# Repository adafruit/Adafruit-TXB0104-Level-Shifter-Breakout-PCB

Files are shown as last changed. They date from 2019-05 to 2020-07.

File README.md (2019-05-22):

## Adafruit TXB0104 Level Shifter Breakout PCB
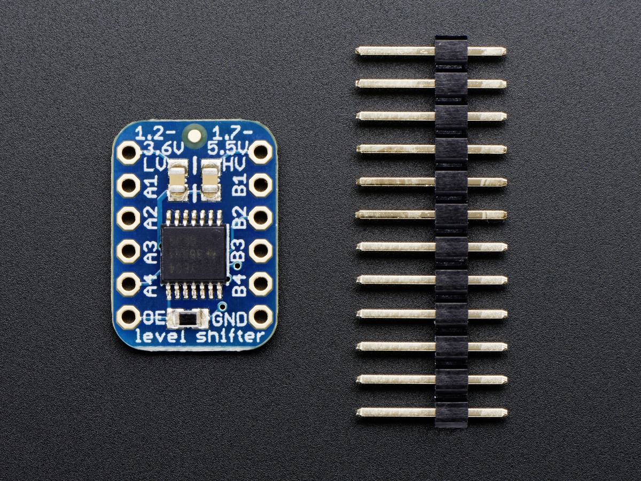
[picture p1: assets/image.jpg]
<a href="http://www.adafruit.com/products/1875"><br/>
Click here to purchase one from the Adafruit shop</a>

This is lovely chip: the TXB0104 bi-directional level converter! This chip perform bidirectional level shifting from pretty much any voltage to any voltage and will auto-detect the direction. Only thing that doesn't work well with this chip is i2c (because it uses strong pullups which confuse auto-direction sensor) or control lines with a lot of capacitance on them. If you need to use pullups, you can but they should be at least 50K ohm - the ones internal to AVRs/Arduino are about 100K ohm so those are OK! Its a little more luxurious than a 74LVX245 but if you just don't want to worry about directional pins this is a life saver!

Since this chip is a special bi-directional level shifter it does not have strong output pins that can drive LEDs or long cables, it's meant to sit on a breadboard between two logic chips! If you do not need instant bi-directional support, we suggest the 74LVX245 as below which has stronger output drive.

PCB files for the Adafruit TXB0104 Level Shifter Breakout. The format is EagleCAD schematic and board layout
- https://www.adafruit.com/product/1875

### License

Adafruit invests time and resources providing this open source design, please support Adafruit and open-source hardware by purchasing products from [Adafruit](https://www.adafruit.com)!

All text above must be included in any redistribution

Designed by Limor Fried/Ladyada for Adafruit Industries.
Creative Commons Attribution/Share-Alike, all text above must be included in any redistribution. 
See license.txt for additional information.

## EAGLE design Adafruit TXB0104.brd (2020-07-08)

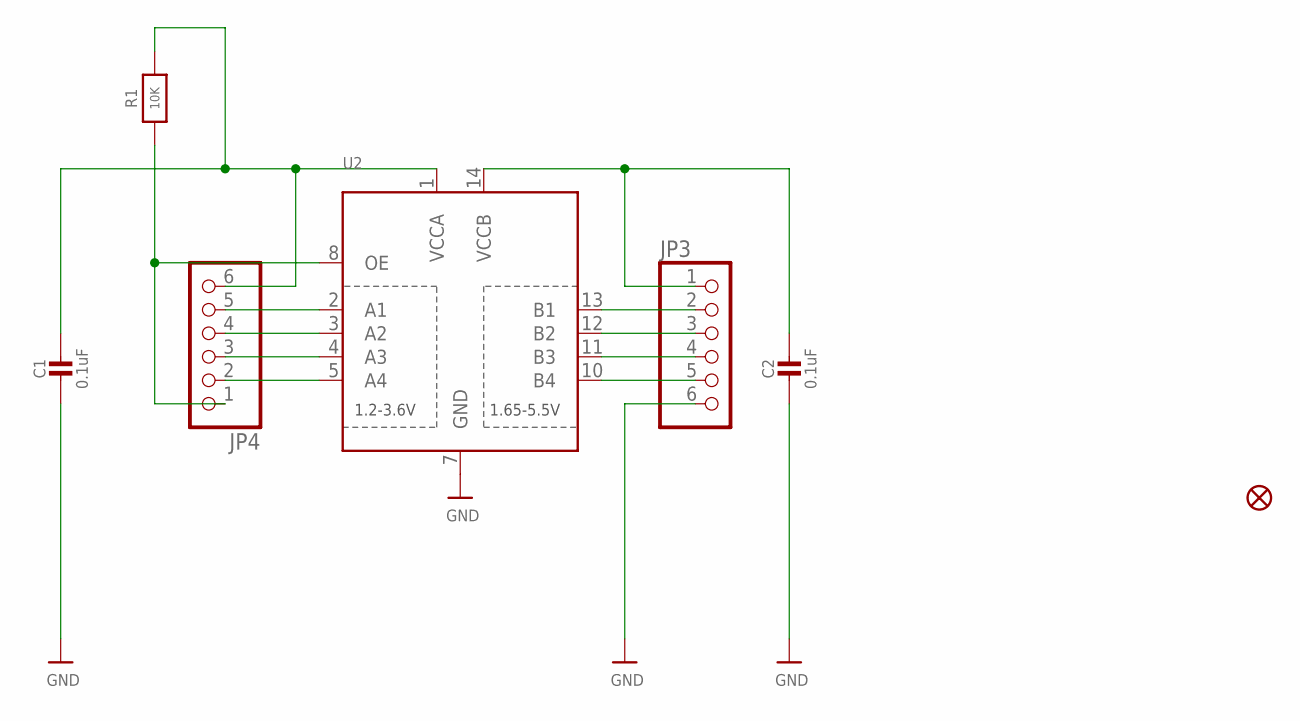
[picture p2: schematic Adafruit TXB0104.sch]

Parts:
C1, C2: 0.1uF; 0805-NO
JP3, JP4: PINHD-1X6CB; 1X06-CLEANBIG
R1: 10K; 0805-NO
U2: TXB0104PWR; TSSOP14
U$5: FIDUCIAL_1MM

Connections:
A1: JP4.5, U2.2 (A1)
A2: JP4.4, U2.3 (A2)
A3: JP4.3, U2.4 (A3)
A4: JP4.2, U2.5 (A4)
B1: JP3.2, U2.13 (B1)
B2: JP3.3, U2.12 (B2)
B3: JP3.4, U2.11 (B3)
B4: JP3.5, U2.10 (B4)
GND: C1.2, C2.2, JP3.6, U2.7 (GND)
OE: JP4.1, R1.1, U2.8 (OE)
VHIGH: C2.1, JP3.1, U2.14 (VCCB)
VLOW: C1.1, JP4.6, R1.2, U2.1 (VCCA)

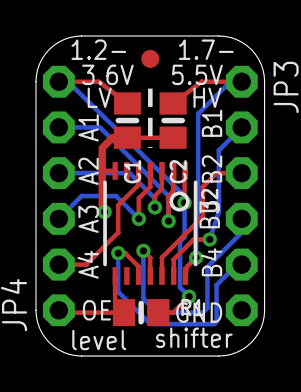
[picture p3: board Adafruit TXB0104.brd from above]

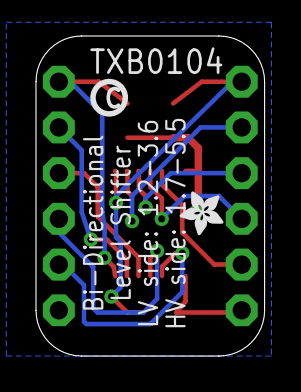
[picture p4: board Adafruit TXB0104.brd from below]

Board: 2 copper layers, 12.7 x 17.8 mm, 9 parts (2 on the bottom side), 12 nets.

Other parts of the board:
U$4: ADAFRUIT_2.5MM
U$7: PCBFEAT-REV-040

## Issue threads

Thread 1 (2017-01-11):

Schematic and PCB error

ngoslee-ttt, 2017-01-11:
The IC symbol for the TXB0104 has GND (pin 7) typed as io instead of pwr. As a result, Eagle is not connecting this pin to the GND net. The PCB has no connection the pin, and the breakout board does not work.
See also: https://forums.adafruit.com/viewtopic.php?f=19&t=108306
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

Nathan

ladyada, 2017-01-11:
hiya, thanks - this was already brought up in an issue and is fixed in next version. email support@adafruit for a refund

ngoslee-ttt, 2017-01-11:
Hiya back,
Yah, you may be referred to the thread I started on your forums. I had thought the design issue was addressed until the post on Jan 05 from adafruit_support_mike so I decided to chase it into the ground.
Nathan
On Jan 11, 2017 1:25 PM, ladyada <notifications@github.com> wrote:hiya, thanks - this was already brought up in an issue and is fixed in next version. email support@adafruit for a refund

—You are receiving this because you authored the thread.Reply to this email directly, view it on GitHub, or mute the thread.

ladyada, 2017-01-11:
all good :)

Closed 2017-01-11.

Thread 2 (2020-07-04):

GND pin not connected

Cyrilanthony777, 2020-07-04:
GND pin on the TXB0104 IC is not connected to PCB GND

ladyada, 2020-07-08:
@kattni please update these with rev C :)

kattni, 2020-07-08:
@Cyrilanthony777 Files have been updated with rev C.

Cyrilanthony777, 2020-07-08:
Thanks :)

Closed 2020-07-08.

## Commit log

2020-07-08 Remove previous version.
    [Adafruit TXB0104.brd]
2020-07-08 Add updated board files.
    [Adafruit TXB0104.brd, Adafruit TXB0104.sch]
